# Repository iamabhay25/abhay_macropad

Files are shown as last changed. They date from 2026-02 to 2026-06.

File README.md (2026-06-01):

<div align="center">

# Abhay's Macropad

### Custom 9-Key Macropad

Custom designed macropad for everyday use.

Features 9 keys with per-key underglow LEDs, a 128×32 SSD1306 OLED display, and a rotary encoder.

<br><br>

Screenshot 2026-05-30 at 3 53 38 PM

<br><br>

| ⚡ RP2040 MC | ⌨️ 9 Keys | ✨ Underlit Keys | 📺 .91" OLED Screen | 🎛️ 1 Rotary Encoder |
|:--:|:--:|:--:|:--:|:--:|

</div>

<br><br><br><br>

<div align="center">

### Sponsored By

<br>

Hack Club

</div>

<br><br><br><br><br>

<div align="center">

### Bill of Materials

<br>

<div align="center">

| Qty | Component | Cost |
|:---:|---|---|
| 4x | [M2.5 Self-Tapping Screws](https://www.aliexpress.us/item/3256805544601650.html) | $1.97 |
| 4x | [M3 Heat-Set Inserts](https://www.aliexpress.us/item/3256808480358197.html) | $1.99 |
| 4x | [M3 Machine Screws](https://www.aliexpress.us/item/2255800784679048.html) | $1.87 |
| 1x | [Seeed Studio XIAO RP2040](https://www.aliexpress.us/item/3256807240972277.html) | $11.73 |
| 1x | [SSD1306 128×32 OLED Display](https://www.aliexpress.us/item/3256805115814136.html) | $2.39 |
| 9x | [Tactile Switches](https://www.aliexpress.us/item/3256808352947766.html) | $3.51 |
| 9x | [Blank White Keycaps](https://www.aliexpress.us/item/3256809017491500.html) | $3.25 |
| 9x | [SOD-123 Diodes](https://www.aliexpress.us/item/3256805388348871.html) | $1.53 |
| 3x | [1206 Capacitors](https://www.aliexpress.us/item/3256807177349573.html) | $1.27 |
| 1x | [0805 Resistor](https://www.aliexpress.us/item/3256809618872827.html) | $1.42 |
| 1x | [Bus Buffer Gate](https://www.aliexpress.us/item/3256807066238250.html) | $1.51 |
| 1x | [Soldering Wire](https://www.aliexpress.us/item/3256806675545472.html) | $1.41 |
| 1x | [Custom PCB](https://jlcpcb.com/) | $3.30 |
| 1x | 3D Printed Case (Printing Legion) | $0.00 |

<br>

**Parts Subtotal:** $35.16

**Fees:** $4.01

**Tax:** $2.96

**Printing Legion Shipping:** $7.00

**Grand Total:** $49.13

<br><br><br><br><br>

<div align="left">
  
### PCB Schematic

<br>

PCB Schematic

<br><br>

### PCB Layout

<br>

<div align="center">

**Top Layer**

<br>

Screenshot 2026-06-01 at 11 23 31 AM

<br><br>

**Bottom Layer**

<br>

Screenshot 2026-06-01 at 11 23 26 AM

<br><br>

**3D View**

<br>

Screenshot 2026-06-01 at 11 56 22 AM

<br><br>

Screenshot 2026-06-01 at 11 56 36 AM

</div>

<br><br>

### Case Design

<br>

<div align="center">

**Top Case**

<br>

Top Case

<br><br>

**Bottom Case**

<br>

Bottom Case

</div>

<br><br>

### Final Assembly

<br>

<div align="center">

Screenshot 2026-05-30 at 3 53 38 PM

</div>

<br><br>

<div align="center">

*Designed and Built by Abhay P.*

</div>

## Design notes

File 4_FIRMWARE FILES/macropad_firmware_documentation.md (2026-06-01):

# Macropad Firmware Documentation 

## Overview

This firmware runs a 9-key macropad built on a Seeed Studio XIAO RP2040 using KMK firmware.

It controls:

* 9 macro keys
* SSD1306 128×32 OLED display
* 9 NeoPixel RGB LEDs (daisy-chained)
* Rotary encoder for volume control

All components work together to handle input, visual output, and system control.

---

## Hardware

### Microcontroller

* Seeed Studio XIAO RP2040

### Display

* SSD1306 OLED (128×32, I2C)
* Address: 0x3C
* Custom lightweight driver using framebuffer

### Input

* 3×3 key matrix (9 keys total)
* Rotary encoder (volume control)

### Output

* 9 NeoPixel LEDs (single daisy-chained strip)

---

## Pin Mapping

### Key Matrix

* Columns: GP26, GP27, GP28
* Rows: GP4, GP2, GP1
* Diode orientation: COL2ROW

### OLED (I2C)

* SDA: GP6
* SCL: GP7
* 400kHz I2C speed

### Encoder

* A: GP29
* B: GP0

### NeoPixel

* Data: GP3
* 9 LEDs in a single chain

---

## Key System

Each key has:

* A label
* A macro or shortcut
* A color
* An index mapping to a bitmap and LED position

### Key actions include:

* Screenshot tools
* Chrome launcher
* Tab recovery
* Force quit
* Lock screen
* Full screenshot
* Spotify launch
* Play/pause
* Spotlight search

---

## Key Press Behavior

When a key is pressed:

1. OLED animation starts
2. LED animation begins across the strip
3. The corresponding macro or shortcut is executed
4. The OLED displays the matching bitmap

When the key is released:

* LED animation clears the strip

---

## OLED System

The OLED uses a framebuffer-based driver.

### Features:

* Text rendering
* Bitmap rendering (128×32 raw images)
* Direct I2C updates

---

## OLED Animation States

### IDLE

* Shows current time in HH:MM format
* Shows date below the time
* Subtle movement in text position

### IN (slide-in)

* Bitmap slides in from the right side
* Smooth transition into view

### HOLD

* Bitmap remains fully visible
* Displayed for approximately 9–10 seconds

### OUT (fade-out)

* Bitmap is cleared using a pixel wipe effect
* Returns to idle clock

---

## LED SYSTEM

The LED system controls 9 NeoPixel LEDs in a single chain.

### Behavior:

* All LEDs are off when idle
* LEDs animate one-by-one when activated
* Each key has a fixed RGB color

### Operation:

#### On key press

* LEDs light sequentially from index 0 up to the selected key index
* Animation runs in small timed steps without blocking input

#### On key release

* LEDs clear sequentially from the active index back to 0

### Control method

* LED updates are handled inside the main scan loop
* Animation runs independently of key processing

---

## LED Animation Engine

The LED system uses a time-based animation controller.

### Fill animation

* LEDs turn on one-by-one from left to right
* Each LED is assigned its key color

### Clear animation

* LEDs turn off one-by-one from right to left

### Timing

* Animation is stepped using millisecond intervals
* No blocking delays are used

---

## Rotary Encoder

Controls system volume:

* Rotate left → volume down
* Rotate right → volume up
* Press (if enabled) → mute toggle

---

## Macros

Some keys execute multi-step macros instead of single shortcuts.

### Example: Spotify

* Opens system search (Spotlight)
* Types "spotify"
* Launches the application

### Example: Chrome

* Opens Spotlight
* Launches Chrome
* Selects a profile (school or personal)

---

## Performance Design

### OLED

* Frame updates are timed to avoid unnecessary refresh
* Animation states control rendering frequency

### LEDs

* LED animation runs inside the keyboard scan loop
* No blocking delays are used during updates

---

## System Flow

1. Key press is detected
2. Macro or shortcut is executed
3. OLED animation is triggered
4. LED animation begins
5. Encoder operates independently for volume control

---

## Summary

This firmware runs a fully integrated macropad system:

* 9 programmable keys
* OLED display with animations
* RGB LED animated feedback per key
* Rotary encoder for volume control

All components run together in a synchronized input-output loop.

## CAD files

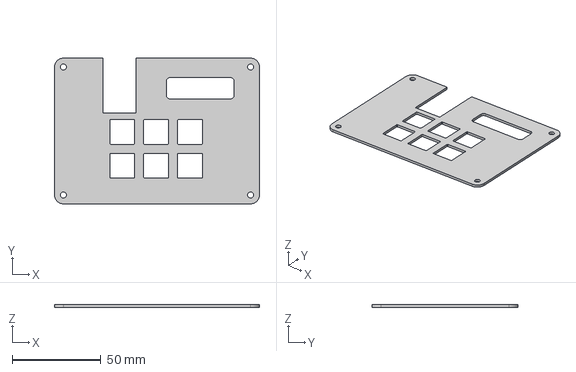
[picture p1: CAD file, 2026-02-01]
Abhay+Macroboard+Top.stp
115.2 x 81.9 x 1.50 mm

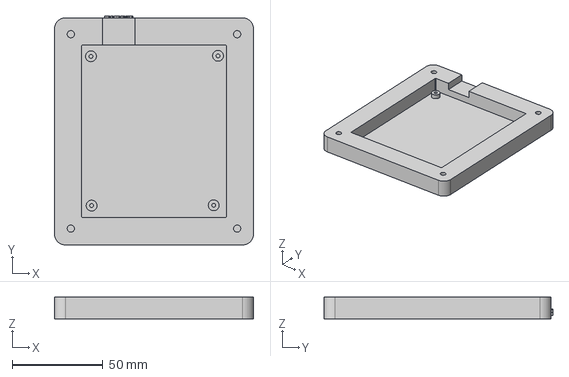
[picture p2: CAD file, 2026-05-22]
CAD/MACROPAD BOTTOM CASE.step
109.7 x 126.2 x 12.0 mm

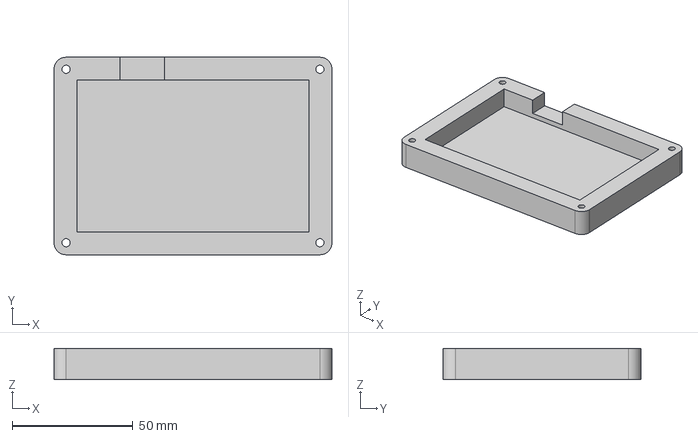
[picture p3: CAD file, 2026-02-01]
Abhay's+Macropad+Bottom.stp
115.2 x 81.9 x 13.0 mm

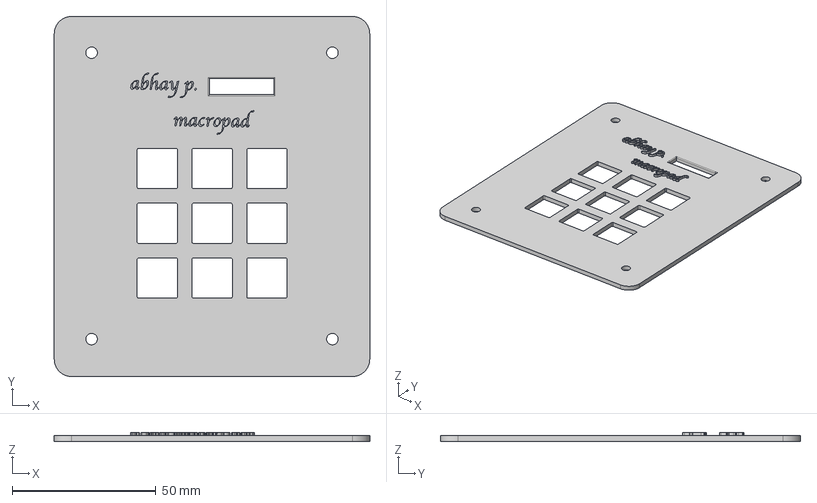
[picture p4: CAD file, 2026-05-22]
CAD/MACROPAD TOP CASE.step
109.7 x 125.2 x 3.00 mm

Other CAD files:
2_CAD FILES/ASSEMBLY/macroboard_assembly.f3z

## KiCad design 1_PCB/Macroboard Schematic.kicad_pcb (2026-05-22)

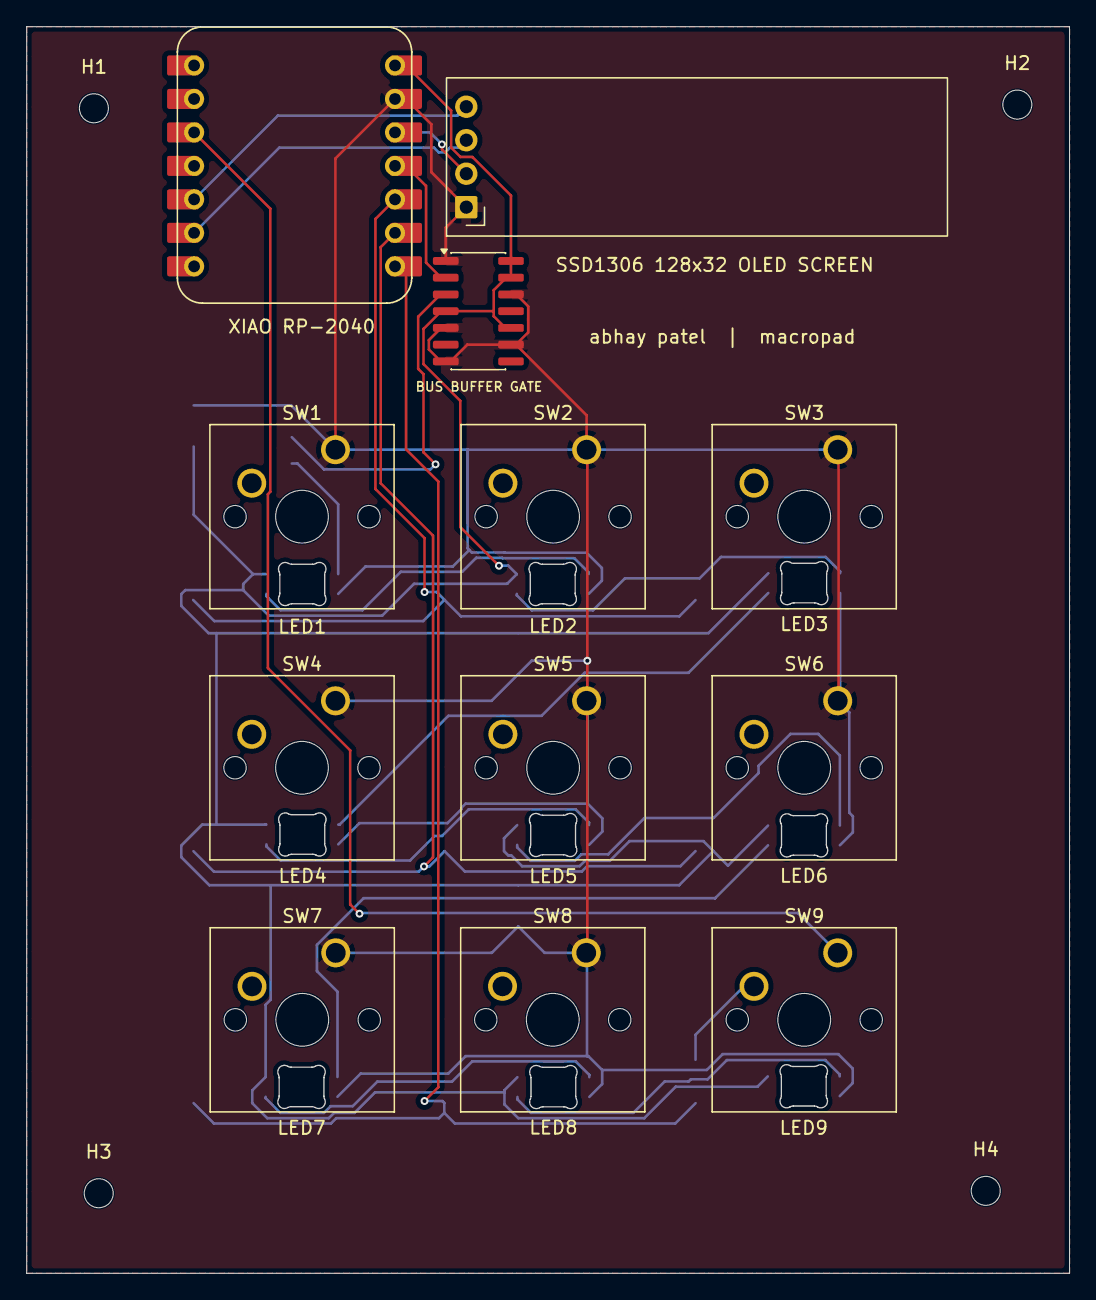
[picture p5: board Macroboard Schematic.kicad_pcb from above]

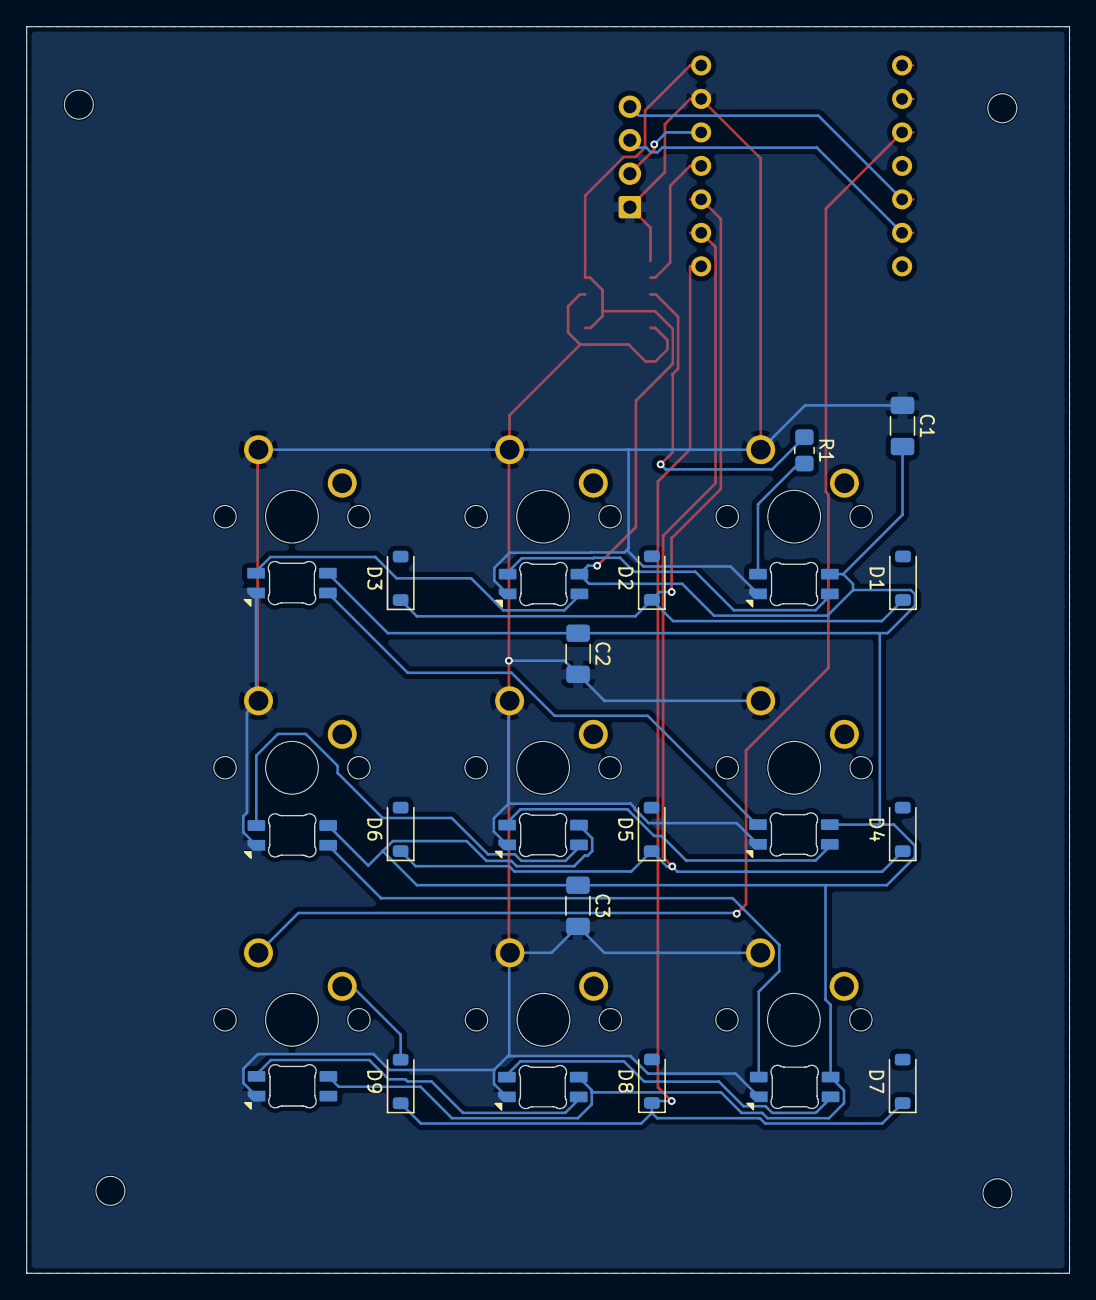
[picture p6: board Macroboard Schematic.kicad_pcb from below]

Board: 2 copper layers, 79.1 x 94.6 mm, 38 parts (22 on the bottom side), 21 nets.

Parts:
BUS BUFFER GATE: 74AHCT125; SOIC-14_3.9x8.7mm_P1.27mm
C1, C2, C3: 100nF; C_1206_3216Metric_Pad1.33x1.80mm_HandSolder
D1, D2, D3, D4, D5, D6, D7, D8, D9: 1N4148W; D_SOD-123
H1, H2, H3, H4: MountingHole; MountingHole_2.2mm_M2
LED1, LED2, LED3, LED4, LED5, LED6, LED7, LED8, LED9: MX_SK6812MINI-E; LED_MX_6028R
R1: 330R; R_0805_2012Metric_Pad1.20x1.40mm_HandSolder
SSD1306 128x32 OLED SCREEN: ER_OLEDM0.91_1x-I2C
SW1, SW2, SW3, SW4, SW5, SW6, SW7, SW8, SW9: SW_Push; SW_Cherry_MX_1.00u_PCB
U3: XIAO-RP2040-DIP

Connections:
+3.3V: SSD1306 128x32 OLED SCREEN.2 (VCC), U3.12 (3V3)
+5V: BUS BUFFER GATE.4, BUS BUFFER GATE.10, BUS BUFFER GATE.13, BUS BUFFER GATE.14 (VCC), C1.2, C2.1, C3.1, LED1.1 (VDD), LED2.1 (VDD), LED3.1 (VDD), LED4.1 (VDD), LED5.1 (VDD), LED6.1 (VDD), LED7.1 (VDD), LED8.1 (VDD), LED9.1 (VDD), U3.14 (VBUS)
COLUMN 3: SW9.1, U3.3 (P28_A2_D2)
GND: BUS BUFFER GATE.1, BUS BUFFER GATE.5, BUS BUFFER GATE.7 (GND), BUS BUFFER GATE.9, BUS BUFFER GATE.12, C1.1, C2.2, C3.2, LED1.3 (VSS), LED2.3 (VSS), LED3.3 (VSS), LED4.3 (VSS), LED5.3 (VSS), LED6.3 (VSS), LED7.3 (VSS), LED8.3 (VSS), LED9.3 (VSS), SSD1306 128x32 OLED SCREEN.1 (GND), SW1.1, SW2.1, SW3.1, SW4.1, SW5.1, SW6.1, SW7.1, SW8.1, U3.13 (GND)
LED: BUS BUFFER GATE.2, U3.11 (P3_D10_MOSI)
unnamed: D9.2 (A), SW9.2
unnamed: LED1.4 (DIN), R1.2
unnamed: LED1.2 (DOUT), LED2.4 (DIN)
unnamed: LED2.2 (DOUT), LED3.4 (DIN)
unnamed: LED3.2 (DOUT), LED4.4 (DIN)
unnamed: LED4.2 (DOUT), LED5.4 (DIN)
unnamed: LED5.2 (DOUT), LED6.4 (DIN)
unnamed: LED6.2 (DOUT), LED7.4 (DIN)
unnamed: LED7.2 (DOUT), LED8.4 (DIN)
unnamed: LED8.2 (DOUT), LED9.4 (DIN)
unnamed: BUS BUFFER GATE.3, R1.1
ROW 1: D1.1 (K), D2.1 (K), D3.1 (K), U3.10 (P4_D9_MISO)
ROW 2: D4.1 (K), D5.1 (K), D6.1 (K), U3.9 (P2_D8_SCK)
ROW 3: D7.1 (K), D8.1 (K), D9.1 (K), U3.8 (P1_D7_RX)
SCL: SSD1306 128x32 OLED SCREEN.3 (SCL), U3.6 (P7_SCL_D5)
SDA: SSD1306 128x32 OLED SCREEN.4 (SDA), U3.5 (P6_SDA_D4)

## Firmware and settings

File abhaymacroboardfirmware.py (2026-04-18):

import board
from kmk.kmk_keyboard import KMKKeyboard
from kmk.keys import KC
from kmk.extensions.neopixel import NeoPixel
from kmk.extensions.oled import Oled, OledDisplayMode
from kmk.modules.tapdance import TapDance
from kmk.modules.macros import Tap, Delay

keyboard = KMKKeyboard()

# --------------------
# KEY PINS
# --------------------
keyboard.col_pins = (
    board.GP26,  # KEY 1
    board.GP27,  # KEY 2
    board.GP28,  # KEY 3
    board.GP29,  # KEY 4
    board.GP6,   # KEY 5
    board.GP7,   # KEY 6
)
keyboard.row_pins = ()
keyboard.diode_orientation = None

# --------------------
# OLED
# --------------------
oled = Oled(
    sda=board.GP6,
    scl=board.GP7,
    i2c_addr=0x3C,
    width=128,
    height=32,
    display_mode=OledDisplayMode.TXT,
)
keyboard.extensions.append(oled)

# --------------------
# RGB (6 LEDs total)
# --------------------
rgb = NeoPixel(
    pin=board.GP3,
    num_pixels=6,
    brightness=0.3,  # lower brightness = cleaner underglow + safer power draw
    auto_write=True,
)
keyboard.extensions.append(rgb)

# Set constant white underglow
rgb.fill((255, 255, 255))

# --------------------
# CHROME TAP DANCE
# --------------------
OPEN_CHROME_SCHOOL = KC.MACRO(
    Tap(KC.LGUI, KC.SPACE), Delay(200), "CHROME", Tap(KC.ENTER), Delay(600),
    *([Tap(KC.TAB)] * 10)
)

OPEN_CHROME_PERSONAL = KC.MACRO(
    Tap(KC.LGUI, KC.SPACE), Delay(200), "CHROME", Tap(KC.ENTER), Delay(600),
    *([Tap(KC.TAB)] * 7)
)

CHROME_SELECTOR = KC.TD(
    OPEN_CHROME_SCHOOL,    # 1 Tap → School
    OPEN_CHROME_PERSONAL   # 2 Taps → Personal
)

# --------------------
# KEYMAP
# --------------------
keyboard.keymap = [
    [
        KC.LGUI(KC.LSHIFT(KC.N4)),              # 1: Screenshot
        CHROME_SELECTOR,                       # 2: Chrome selector
        KC.LGUI(KC.LSHIFT(KC.T)),              # 3: Reopen Tab
        KC.LGUI(KC.LALT(KC.ESC)),              # 4: Force Quit
        KC.LCTRL(KC.LGUI(KC.Q)),               # 5: Lock Screen
        KC.LGUI(KC.LSHIFT(KC.N4), KC.SPACE),   # 6: Screenshot Whole Screen
    ]
]

if __name__ == "__main__":
    keyboard.go()

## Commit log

2026-02-01 Rename Macroboard Schematic.kicad_pcb to PCB/Macroboard Schematic.kicad_pcb
    [Macroboard Schematic.kicad_pcb]
2026-02-01 Rename Macroboard Schematic.kicad_pro to PCB/Macroboard Schematic.kicad_pro
2026-02-01 Rename Macroboard Schematic.kicad_sch to PCB/Macroboard Schematic.kicad_sch
    [Macroboard Schematic.kicad_sch]
2026-02-01 Update and rename Abhay's+Macropad+Bottom.stp to CAD/Abhay's+Macropad+Bottom.stp
    [Abhay's+Macropad+Bottom.stp]
2026-02-01 Update and rename Abhay+Macroboard+Top.stp to CAD/Abhay+Macroboard+Top.stp
    [Abhay+Macroboard+Top.stp]
2026-02-06 updating to current cad files
    [Abhay's+Macropad+Bottom.stp, Abhay+Macroboard+Top.stp]
2026-02-06 updated to current stp files
    [Abhay's+Macropad+Bottom.stp, Abhay+Macroboard+Top.stp]
2026-02-10 Implement LED blinking functions with threading
    Added LED blinking functionality with threading support.
2026-03-23 Update README with additional images and BOM
2026-03-23 Rename Wireless Keyboard.kicad_pcb to PCB/Wireless Keyboard.kicad_pcb
    [Wireless Keyboard.kicad_pcb]
2026-03-23 Rename Wireless Keyboard.kicad_pro to PCB/Wireless Keyboard.kicad_pro
2026-04-18 Modify BOM and update macroboard images
    Updated the Bill of Materials and replaced images for the macroboard assembly.
2026-04-18 Rename Abhay Macroboard Top.step to CAD/Abhay Macroboard Top.step
    [Abhay Macroboard Top.step]
2026-04-18 Rename Abhay's Macropad Bottom.step to CAD/Abhay's Macropad Bottom.step
    [Abhay's Macropad Bottom.step]
2026-04-18 Rename macroboard assembly.f3z to ASSEMBLY/macroboard assembly.f3z
    [macroboard assembly.f3z]
2026-05-22 Rename MACROPAD BOTTOM CASE.step to CAD/MACROPAD BOTTOM CASE.step
    [MACROPAD BOTTOM CASE.step]
2026-05-22 Rename MACROPAD TOP CASE.step to CAD/MACROPAD TOP CASE.step
    [MACROPAD TOP CASE.step]
2026-05-31 Update print statement from 'Hello' to 'Goodbye'
2026-06-01 Rename macroboard assembly.f3z to macroboard_assembly.f3z
    [macroboard_assembly.f3z]
2026-06-01 Rename Macroboard Schematic.kicad_pcb to Macroboard Schematic.kicad_pcb
    [Macroboard Schematic.kicad_pcb]
2026-06-01 Rename Macroboard Schematic.kicad_pro to Macroboard Schematic.kicad_pro
2026-06-01 Rename ASSEMBLY/macroboard_assembly.f3z to 2_CAD FILES/ASSEMBLY/macroboard_assembly.f3z
    [macroboard_assembly.f3z]
